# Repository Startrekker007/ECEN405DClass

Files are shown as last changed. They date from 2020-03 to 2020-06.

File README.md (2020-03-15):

# ECEN405DClass
This repository contains the documentation and designs for the Class D Amplifier design project for ECEN405.

## Directories
The Altium_Kicad directory contains circuit schematics.

The LTSpice dir contains all simulation schematics on LTSpiceXVII.

Assignment dir contains draft assignments

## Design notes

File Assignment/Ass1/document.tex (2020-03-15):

\documentclass[]{article}
\usepackage{float}
\usepackage{multicol}
\usepackage[a4paper, margin=0.68in]{geometry}
\usepackage[siunitx]{circuitikz}
\usepackage{siunitx}
\usepackage{tikz}
\usetikzlibrary{shapes,arrows}
\usepackage{verbatim}
\usepackage{lscape}
\usepackage{listings}
\usepackage{courier}
\usepackage{gensymb}
\usepackage{amsmath,amsfonts,mathtools,amssymb}
%opening
\title{ECEN405 Assignment 1}
\author{Keshav Raj 300418412\\Lab Partner: Tim Loretto}

\begin{document}
\tikzstyle{block} = [draw, fill=blue!20, rectangle, 
minimum height=3em, minimum width=6em]
\tikzstyle{sum} = [draw, fill=blue!20, circle, node distance=1cm]
\tikzstyle{input} = [coordinate]
\tikzstyle{output} = [coordinate]
\tikzstyle{pinstyle} = [pin edge={to-,thin,black}]
\maketitle

\begin{multicols}{2}
	\section{Question 1}
	\subsection{a)}
	In order to ensure 80W can be delivered to a $4\Omega$ impedance load, a value for the full voltage swing range must be calculated which allows enough current to flow through the load to dissipate 80W through it. The voltage must be within 33V which is the maximum that one channel of the power supply can output and the current must be less than 6A which is the maximum two of the banks hooked in parallel can output.
	The following is the calculation of the required values:
	\begin{equation*}
	\begin{split}
	80&=IV\\
	80&=4I^2\\
	\frac{80}{V}&=I\\
	80&=4\left( \frac{80}{V} \right)^2\\
	80&=4\left( \frac{6400}{V^2} \right)\\
	80&=\frac{25600}{V^2}\\
	\frac{25600}{80}&=V^2\\
	V&=\sqrt{320}\\
	V&=17.888V\\
	I&=4.472A\\  
	\end{split}
	\end{equation*}
	\subsection{b)}
	In order to achieve the 10Hz to 200Hz bandwidth, firstly the triangle wave generator must be a high enough frequency to modulate the input signal without causing any aliasing. In order to ensure this, the triangle wave must be at least 10 times greater than the highest frequency component of the input signal. However, without filtering the input, we cannot be sure what the highest frequency component could be, therefore a bandpass filter at the input is required. The following constitutes the design for a cascaded sallen-key lowpass and high pass filter which are both chebyshev 3th order filters.
\end{multicols}
	\begin{figure}[H]
		\centering
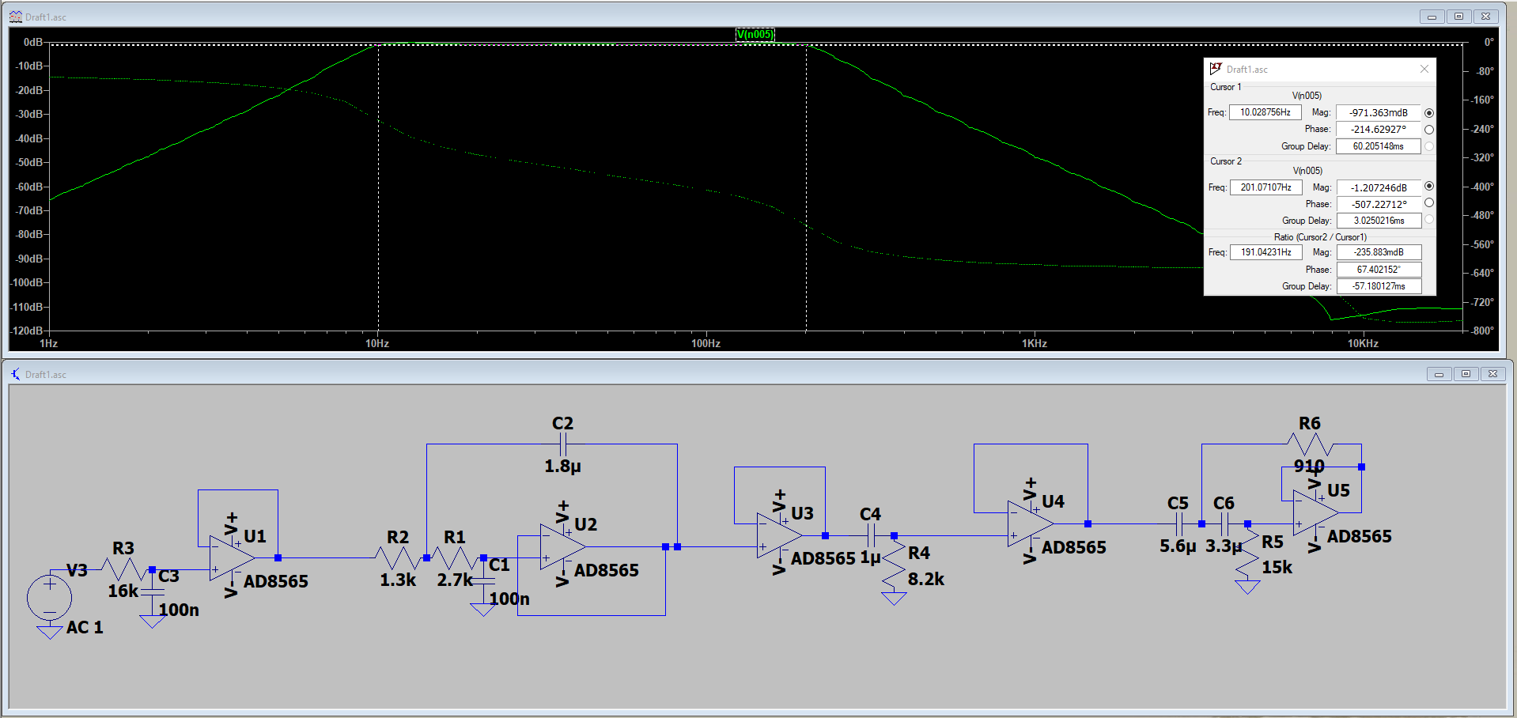
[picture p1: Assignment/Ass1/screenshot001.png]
		
		\caption{Designed Filter simulated in LTSpice}
		\label{fig:screenshot001}
	\end{figure}
\begin{multicols}{2}
	This would mean that the triangle wave can now be at a frequency of 2000Hz or greater to ensure correct modulation of the input signal.
	\subsection{c)}
	In order to ensure that a signal of 1V amplitude (or 2Vpp) can be modulated, the input triangle wave to the comparator must have an amplitude of slightly over 2V to prevent output saturation. A value of 2.1V for the maximum amplitude of the triangle wave will suffice. If the triangle wave's amplitude is unable to be easily adjusted, the passband gain of the input filters can instead be adjusted to achieve the same required comparator level.
	The triangle wave from the oscillator will have a DC offset that will likely be around 1V. This can either be AC coupled which will distort the triangle wave (as it is not a pure sinusoid) or the input signal can be offset as well to the same level, this can either be done using a clamping circuit (not preferred), a simple voltage divider with a DC decoupling capacitor or a summing amplifier. It is preferred to use a summing amplifier as the clamping circuit is difficult to implement while the decoupling capacitor acts as an extra low pass filter which may alter the expected spectrum of the input signal.
	These additions will ensure that the input signal and the triangle wave can be compared to each other easily with the comparator and ensure a full swing of PWM duty cycle with minimal wave clipping on the output.\\
	As gate driver generally accept a 3.3V or 5V logic signal, this PWM output must be amplified to one of the logic standards, this can be done with a simple non-inverting amplifier.
\end{multicols}
	\section{Q2}
	The following diagram shows the selected design:
	\begin{figure}[H]
		\centering
		
		\caption{D Class amplifier design}
		\label{fig:untitled-diagram-4}
	\end{figure}
\begin{multicols}{2}
	The first input low pass filter is a 3rd order chebyshev sallen-key topology filter. The output from this filter is cascaded with a voltage follower to a 10Hz high pass filter of the same type as the first low pass filter. The output from here can be offset if required to match the same offset of the triangle wave oscillator output.\\
	The triangle wave oscillator consists of a circuit that generates a triangle wave offset at a settable voltage, amplitude and frequency of oscillation using two trimmer potentiometers.\\
	The input signal after filtering is connected to the non-inverting input of the comparator while the triangle wave is connected to the inverting input of the comparator.
	The output of the comparator can be pulled high to a logic voltage using a pull-up resistor which can then be connected to a gate drivers' logic inputs.\\
	To realise a full bridge toplogy, two gate drivers are required to drive all the MOSFETs in the bridge. These driver's outputs are connected to the gates of the H-bridge with two bootstrap circuits for each pair of MOSFETs each gate driver is driving.\\
	Finally the output of the bridge will be connected to a high current low pass LC filter to filter out the PWM waveform and get back the modulated waveform. The cut off frequency of the LC filter can be as low as 200Hz however must be much lower than 2000Hz to ensure no spectral components of the PWM wave remains.\\
	\section{Q3}
	The decision of having a half bridge vs a full bridge topology consists of weighing what is most important in terms of features.\\
	A half bridge topology has the advantages of having lesser switching MOSFETs and therefore far lower switching and conduction losses resulting in an overall more efficient design. The disadvantages are that it requires feedback from the output signal to the input signal to ensure correct operation. It also requires a negative power supply rail which can be difficult to implement if more current is required from the power supply.\\
	A full bridge topology has the advantage of being open loop and doesn't require any feedback. The output voltage will swing from Vdd to GND and will not have any DC offset if correctly filtered.
	It therefore only requires a single power supply channel to realise. Overall it is infact easier to correctly implement and could potentially be more reliable.
	It's disadvantages include higher switching losses, requirement of an extra gate driver and more MOSFETs.\\
	In the end the full bridge topology was chosen in favor of simplicity and reliability and better audio quality. The output voltage swing is also preferably Vdd to GND and a separate negative rail is not required.
\end{multicols}

\end{document}

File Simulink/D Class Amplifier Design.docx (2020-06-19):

# D Class Amplifier Design

# Introduction

The development of power amplifiers is a very important in several applications within both engineering and music where they are used to drive high power motors or audio speakers. This report outlines our attempt at designing and simulating a D class amplifier with the specifications stated below:

- Input sensitivity: +-1V
- Power Output: 80W
- Twin 32V 3A power supply driven
- Bandwidth: 10Hz-200Hz Subwoofer specification

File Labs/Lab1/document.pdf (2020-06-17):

ECEN405 LAB 1 KESHAV RAJ 300418412 | 1

# ECEN405 Lab 1

Keshav Raj 300418412
Lab Partner: Tim Loretto
I. DELIVERABLES
A. 1)

30k =

10k
32.8k(1k)C1

30k =

10k
32.8M C1
1
C1

=

30k · 32.8M
10k

C1 =

10k
30k · 32.8M
C1 = 10.1626nF
C1 u 10nF
B. 2)
In order to find the minimum frequency, R3 needs to be minimized and R4 needs to be maximized. By entering the formula into desmos and assigning R3 to be the X axis and R4 an adjustable slider, the entire range of frequencies can be investigated.

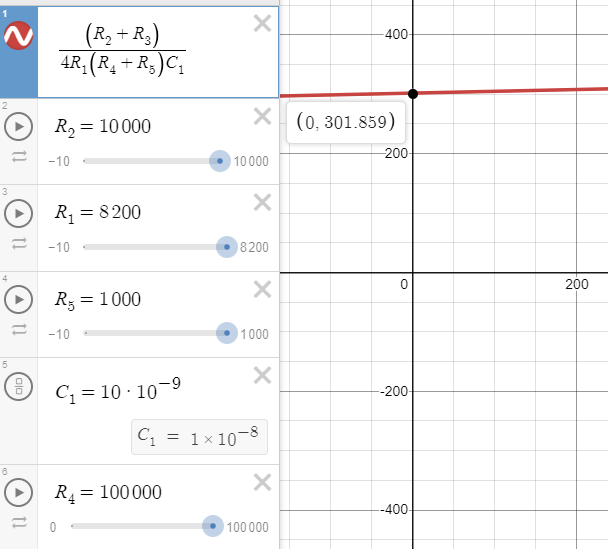
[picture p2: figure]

Fig. 1. Minimum frequency at R3 = 0Ω and R4 = 100kΩ

Fig. 2. Maximum frequency when R3 = 1MΩ and R4 = 0Ω

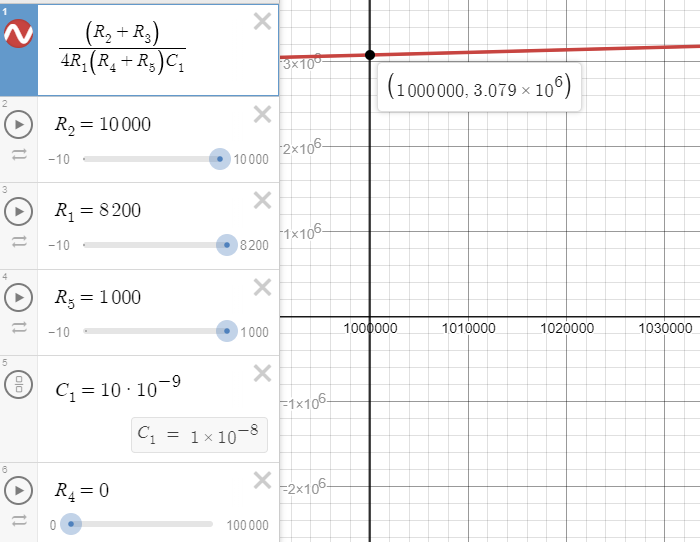
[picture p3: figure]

These two figures show that the minimum frequency is 301Hz while the max is 3MHz.

C. 3)

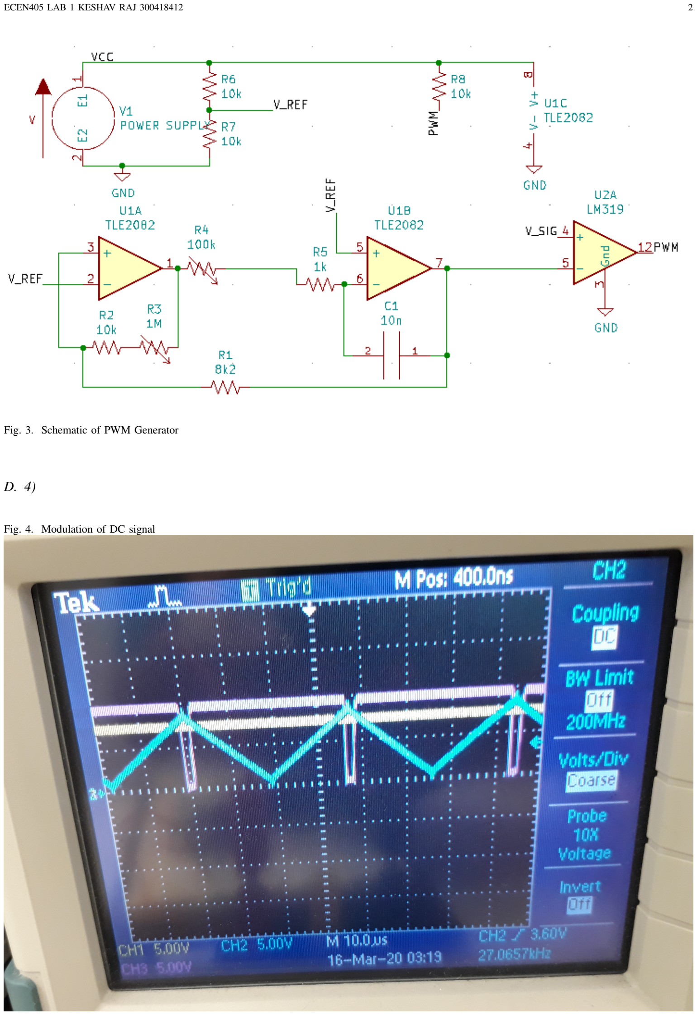
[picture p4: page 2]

Fig. 3. Schematic of PWM Generator

D. 4)

Fig. 4. Modulation of DC signal

E. 5)
All op-amps have a drop off in gain with increasing frequency, eventually as the frequency gets so high, the opamp’s gain attenuates too much too be seen on the output. Also the frequency response of some of the components used such as the resistors and capacitors would prevent the realization of high frequency signals and would most likely just filter them out.
F. 6)

Rather than having a single comparator, one can have two with the second one with its inputs swapped (input signal goes to inverting input and triangle wave goes to non-inverting input), this would allow a non-inverted and an inverted signal to be generated. Otherwise one could use a logic inverter to achieve the same.

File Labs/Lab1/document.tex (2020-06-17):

\documentclass[]{IEEEtran}
\usepackage{float}
\usepackage{multicol}
\usepackage[a4paper, margin=0.68in]{geometry}
\usepackage{color} %red, green, blue, yellow, cyan, magenta, black, white
\definecolor{mygreen}{RGB}{28,172,0} % color values Red, Green, Blue
\definecolor{mylilas}{RGB}{170,55,241}
\usepackage[siunitx]{circuitikz}
\usepackage{siunitx}
\usepackage{verbatim}
\usepackage{lscape}
\usepackage{listings}
\usepackage{courier}
\usepackage{gensymb}
\usepackage{amsmath,amsfonts,mathtools,amssymb}
%opening
\title{ECEN405 Lab 1}
\author{Keshav Raj 300418412\\Lab Partner: Tim Loretto}

\begin{document}
	\onecolumn
\lstset{language=Matlab,%
	%basicstyle=\color{red},
	breaklines=true,%
	morekeywords={matlab2tikz},
	keywordstyle=\color{blue},%
	morekeywords=[2]{1}, keywordstyle=[2]{\color{black}},
	identifierstyle=\color{black},%
	stringstyle=\color{mylilas},
	commentstyle=\color{mygreen},%
	showstringspaces=false,%without this there will be a symbol in the places where there is a space
	numbers=left,%
	numberstyle={\tiny \color{black}},% size of the numbers
	numbersep=9pt, % this defines how far the numbers are from the text
	emph=[1]{for,end,break},emphstyle=[1]\color{red}, %some words to emphasise
	%emph=[2]{word1,word2}, emphstyle=[2]{style},    
}
\maketitle
\markboth{ECEN405 LAB 1 KESHAV RAJ 300418412}
{}

\begin{multicols}{2}
\section{Deliverables}
\subsection{1)}
\begin{equation*}
	\begin{split}
		30k&=\frac{10k}{32.8k(1k)C_1}\\
		30k&=\frac{10k}{32.8M\ C_1}\\
		\frac{1}{C_1}&=\frac{30k\cdot32.8M}{10k}\\
		C_1&=\frac{10k}{30k\cdot32.8M}\\
		C_1&=10.1626nF\\
		C_1&\approxeq10nF\\
		\end{split}
\end{equation*}
\subsection{2)}
In order to find the minimum frequency, $R_3$ needs to be minimized and $R_4$ needs to be maximized. By entering the formula into desmos and assigning $R_3$ to be the X axis and $R_4$ an adjustable slider, the entire range of frequencies can be investigated.
\begin{figure}[H]
	\centering
	\caption{Minimum frequency at $R_3=0\Omega$ and $R_4=100k\Omega$}
	\label{fig:screenshot001}
	
\end{figure}
\begin{figure}[H]
	\centering
	\caption{Maximum frequency when $R_3=1M\Omega$ and $R_4=0\Omega$}
	\label{fig:screenshot002}
	
\end{figure}
These two figures show that the minimum frequency is 301Hz while the max is 3MHz.
\subsection{3)}

\end{multicols}
\begin{figure}[H]
	\centering
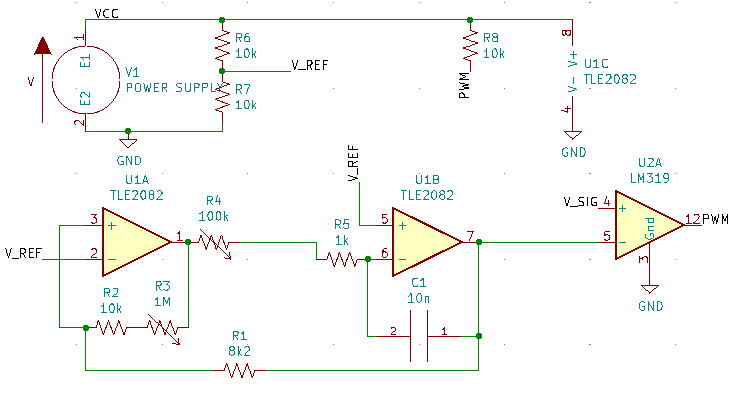
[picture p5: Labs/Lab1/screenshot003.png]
	
	\caption{Schematic of PWM Generator}
	\label{fig:screenshot003}
\end{figure}
\begin{multicols}{2}
	
\end{multicols}
	\subsection{4)}

\begin{figure}[H]
	\centering
	\caption{Modulation of DC signal}
	\label{fig:crossing}
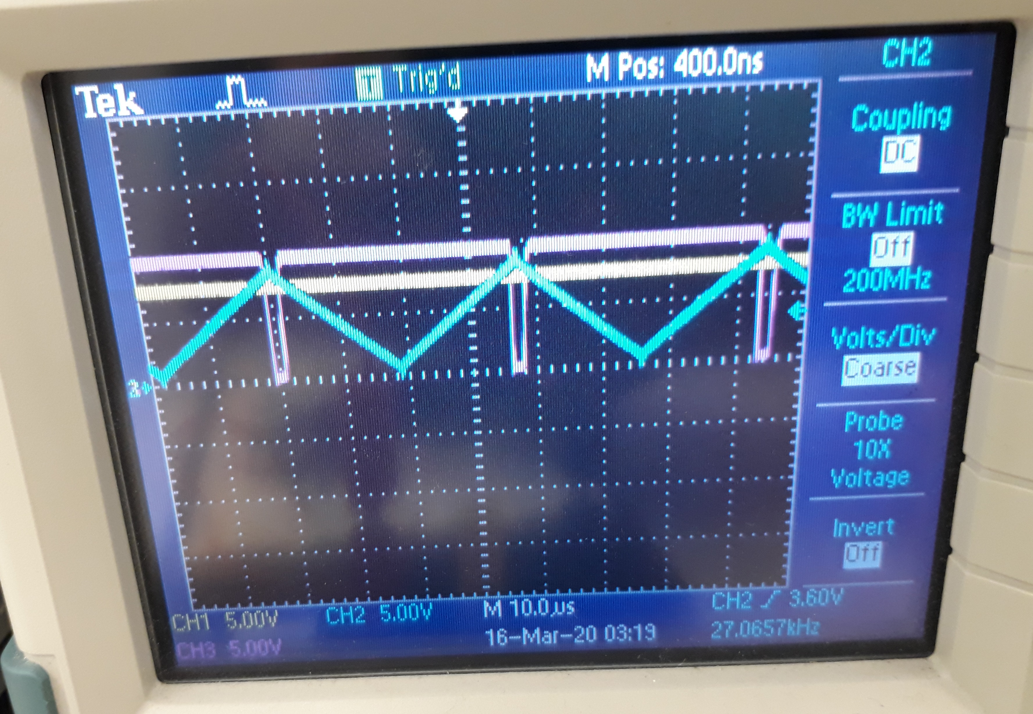
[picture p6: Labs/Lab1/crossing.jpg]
	
\end{figure}
	
\begin{multicols}{2}
	\subsection{5)}
	All op-amps have a drop off in gain with increasing frequency, eventually as the frequency gets so high, the op-amp's gain attenuates too much too be seen on the output. Also the frequency response of some of the components used such as the resistors and capacitors would prevent the realization of high frequency signals and would most likely just filter them out.
	\subsection{6)}
	Rather than having a single comparator, one can have two with the second one with its inputs swapped (input signal goes to inverting input and triangle wave goes to non-inverting input), this would allow a non-inverted and an inverted signal to be generated. Otherwise one could use a logic inverter to achieve the same.
\end{multicols}

\end{document}

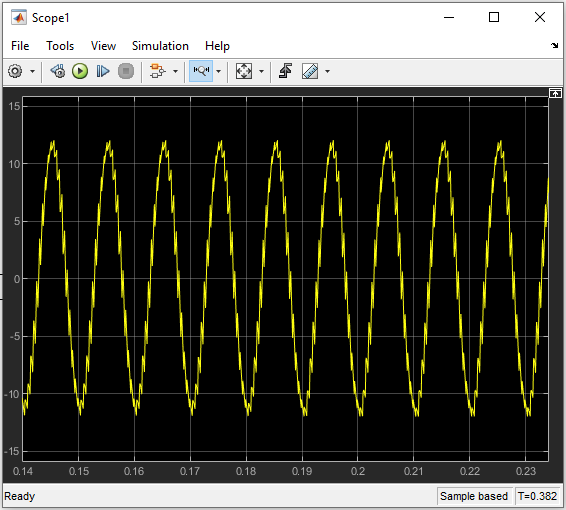
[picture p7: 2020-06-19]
Simulink/FinalPostFilterAdjustment.png

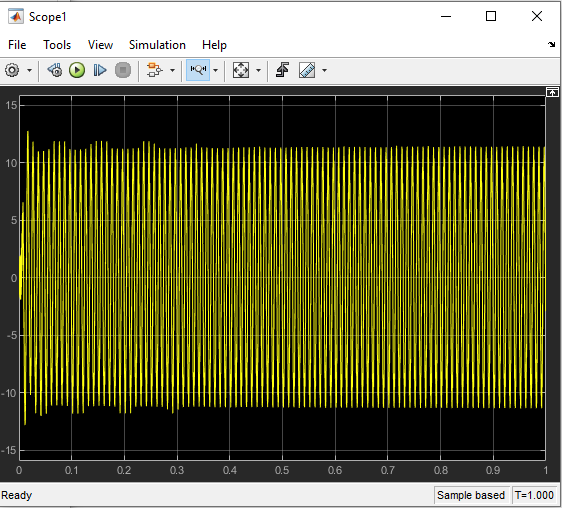
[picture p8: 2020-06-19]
Simulink/FinalOutput.png

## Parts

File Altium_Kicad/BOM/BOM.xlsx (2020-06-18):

ID | Component | Value | Quantity | Price Per Pack | No in Pack | Packs | Total Cost | Link
1 | Capacitor | 10n | 3 | 0.14 | 1 | 3 | 0.42 | https://nz.element14.com/multicomp/mc0805b103k500a5-08mm/ceramic-capacitor-0-01uf-50v-x7r/dp/1694099
2 | Capacitor | 100u | 1 | 0.92 | 1 | 1 | 0.92 | https://nz.element14.com/panasonic-electronic-components/eeufm1h101/aluminum-electrolytic-capacitor/dp/1219478
3 | Capacitor | 10u | 2 | 0.09 | 1 | 2 | 0.18 | https://nz.element14.com/multicomp/mcgpr63v106m5x11/cap-10-f-63v-20/dp/9451480
4 | Capacitor | 22u | 1 | 0.62 | 1 | 1 | 0.62 | https://nz.element14.com/panasonic/eeufm1h220/cap-22-f-50v-20/dp/1848399
5 | Capacitor | 1.8u ~ 1.5u | 1 | 1.75 | 5 | 1 | 1.75 | https://nz.element14.com/panasonic/ecea1hka1r5/cap-1-5-f-50v-20/dp/1902069
6 | Capacitor | 100n | 2 | 0.3 | 1 | 2 | 0.6 | https://nz.element14.com/multicomp/mc0805b104k500a2-54mm/capacitance-0-1-f/dp/2309020
7 | Capacitor | 5.6u | 1 | 0.64 | 1 | 1 | 0.64 | https://nz.element14.com/panasonic/eeufc2a5r6/cap-5-6-f-100v-20/dp/2805606
8 | Capacitor | 3.3u | 1 | 0.24 | 1 | 1 | 0.24 | https://nz.element14.com/united-chemi-con/ekmg201ell3r3mf11d/capacitor-alum-elec-3-3uf-200v/dp/1686773
9 | Capacitor | 1u | 1 | 0.09 | 1 | 1 | 0.09 | https://nz.element14.com/multicomp/mcrh63v105m5x11/cap-1-f-63v-20/dp/9452001
10 | Capacitor | 160u ~ 180u | 1 | 1.15 | 1 | 1 | 1.15 | https://nz.element14.com/panasonic/eeufr1v181b/cap-180-f-35v-20/dp/2479892
11 | Diode | 1N4007 | 2 | 0.12 | 1 | 2 | 0.24 | https://nz.element14.com/multicomp-pro/1n4007/diode-standard-recovery-1a-1kv/dp/230635701?st=1N4007
12 | Gate Driver | HIP4082IPZ | 1 | 8.26 | 1 | 1 | 8.26 | https://nz.rs-online.com/web/p/mosfet-drivers/0859391/
13 | Terminal Block |  | 2 | 1.78 | 1 | 2 | 3.56 | https://nz.element14.com/camdenboss/ctb5050-2/terminal-block-wire-to-brd-2pos/dp/2315342
14 | SMA |  | 1 | 6.77 | 1 | 1 | 6.77 | https://nz.element14.com/molex/73251-1150/rf-coax-conn-sma-jack-50-ohm-pcb/dp/1909295?st=sma
15 | Inductor | 1m | 1 | 10.56 | 1 | 1 | 10.56 | https://nz.rs-online.com/web/p/leaded-inductors/4890318/
16 | MOSFETS | STP40NF03L | 4 | 1.24 | 1 | 4 | 4.96 | https://nz.element14.com/stmicroelectronics/stp40nf03l/mosfet-n-to-220/dp/9803149
17 | Resistor | 10k | 4 | 0.04 | 1 | 4 | 0.16 | https://nz.element14.com/multicomp/mcmf0w8ff1002a20/metal-film-resistor-10kohm-125mw/dp/1127017
18 | resistor | 30k | 1 | 0.06 | 1 | 1 | 0.06 | https://nz.element14.com/multicomp/mf50-30k/res-30k-1-500mw-axial-metal-film/dp/9340378
19 | Resistor | 1k | 1 | 0.04 | 1 | 1 | 0.04 | https://nz.element14.com/multicomp/mccfr0s2j0102a20/carbon-film-resistor-1kohm-500mw/dp/1127904
20 | Resistor | 8.2k | 2 | 0.06 | 1 | 2 | 0.12 | https://nz.element14.com/multicomp/mf50-8k2/res-8k2-1-500mw-axial-metal-film/dp/9340947
21 | Resistor | 3.9k | 2 | 0.06 | 1 | 2 | 0.12 | https://nz.element14.com/multicomp/mf50-3k9/res-3k9-1-500mw-axial-metal-film/dp/9340521
22 | Resistor | 1.3k | 1 | 0.03 | 1 | 1 | 0.03 | https://nz.element14.com/multicomp/mccfr0w4j0132a50/carbon-film-resistor-1-3kohm-250mw/dp/1128774
23 | Resistor | 2.7k | 1 | 0.02 | 1 | 1 | 0.02 | https://nz.element14.com/multicomp/mcmf0w8ff2701a20/metal-film-resistor-2-7kohm-125mw/dp/1129191
24 | resistor | 16k | 1 | 0.06 | 1 | 1 | 0.06 | https://nz.element14.com/multicomp/mf50-16k/res-16k-1-500mw-axial-metal-film/dp/9340068
25 | Resistor | 910R | 1 | 0.06 | 1 | 1 | 0.06 | https://nz.element14.com/multicomp/mf50-910r/res-910r-1-500mw-axial-metal-film/dp/9340980
26 | Resistor | 15k | 1 | 0.03 | 1 | 1 | 0.03 | https://nz.element14.com/multicomp-pro/mcmf0w4ff1502a50/metal-film-resistor-15kohm-250mw/dp/112693801
27 | Resistor | 5k | 1 | 0.55 | 1 | 1 | 0.55 | https://nz.element14.com/multicomp-pro/mcmf0w4bb5001a50/metal-film-resistor-5kohm-250mw/dp/160205801
28 | Switch | OS102011MS2QN1C | 1 | 1.31 | 1 | 1 | 1.31 | https://nz.rs-online.com/web/p/slide-switches/7874864/
29 | OOOP AMP | LM324N | 3 | 1.36 | 1 | 3 | 4.08 | https://nz.element14.com/on-semiconductor/lm324n/ic-op-amp-quad-dip14-324/dp/1417640?st=LM324N
30 | Comparator | MCP6541-E/P | 1 | 0.94 | 1 | 1 | 0.94 | https://nz.element14.com/microchip/mcp6541-e-p/comparator-single-push-pull-dip8/dp/1332135
31 | LR | LM7805CT | 1 | 1.09 | 1 | 1 | 1.09 | https://nz.element14.com/stmicroelectronics/l7805abv/ic-v-reg-5v/dp/1467758
32 | SMR | R-785.0-0.5 | 1 | 14.57 | 1 | 1 | 14.57 | https://nz.element14.com/recom-power/r-785-0-0-5/converter-dc-dc-5v-3w/dp/1793142
33 | LR | LM7812CT | 1 | 1.28 | 1 | 1 | 1.28 | https://nz.element14.com/on-semiconductor/mc7812ctg/ic-v-reg-12v-7812-to-220-3/dp/9666109
34 | Inverter | SN74HC04N | 1 | 1.15 | 1 | 1 | 1.15 | https://nz.element14.com/texas-instruments/sn74hc04n/ic-hex-inverter-74hc04-dip14-5v/dp/3120432
TOTAL COST
66.63

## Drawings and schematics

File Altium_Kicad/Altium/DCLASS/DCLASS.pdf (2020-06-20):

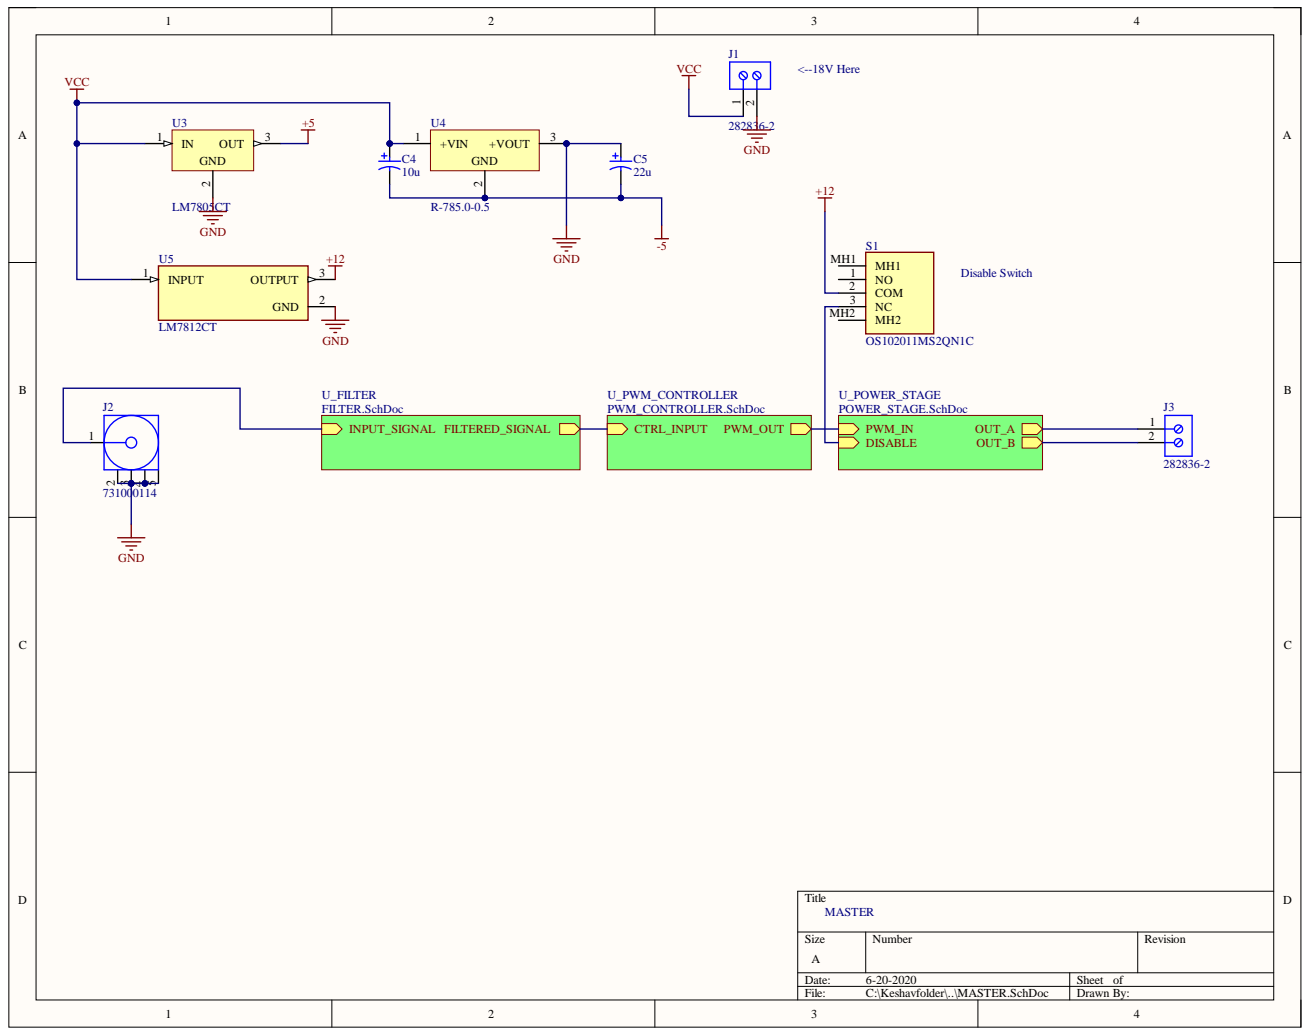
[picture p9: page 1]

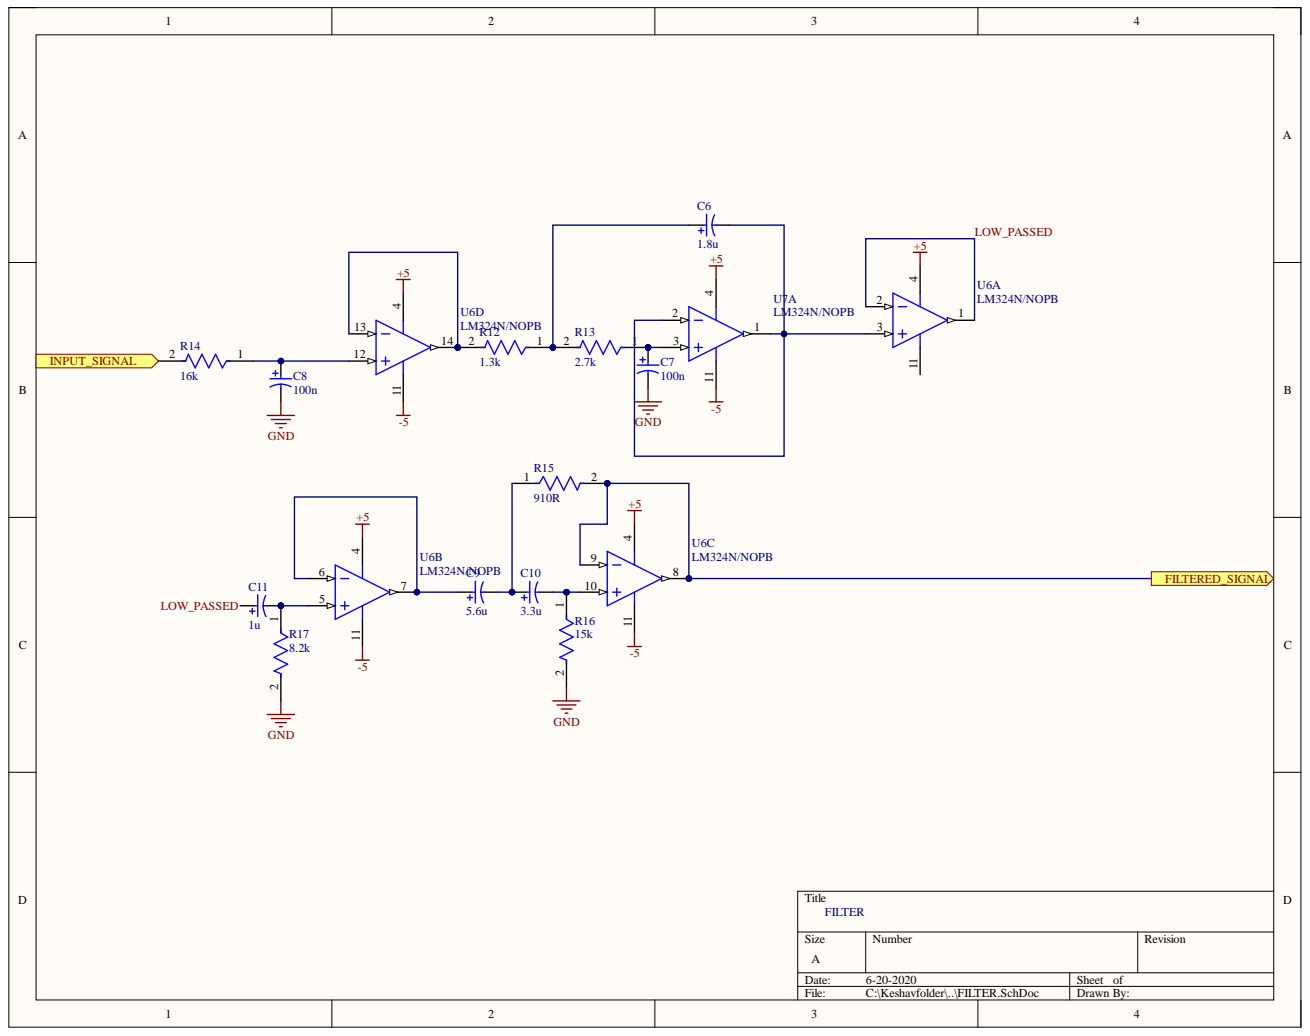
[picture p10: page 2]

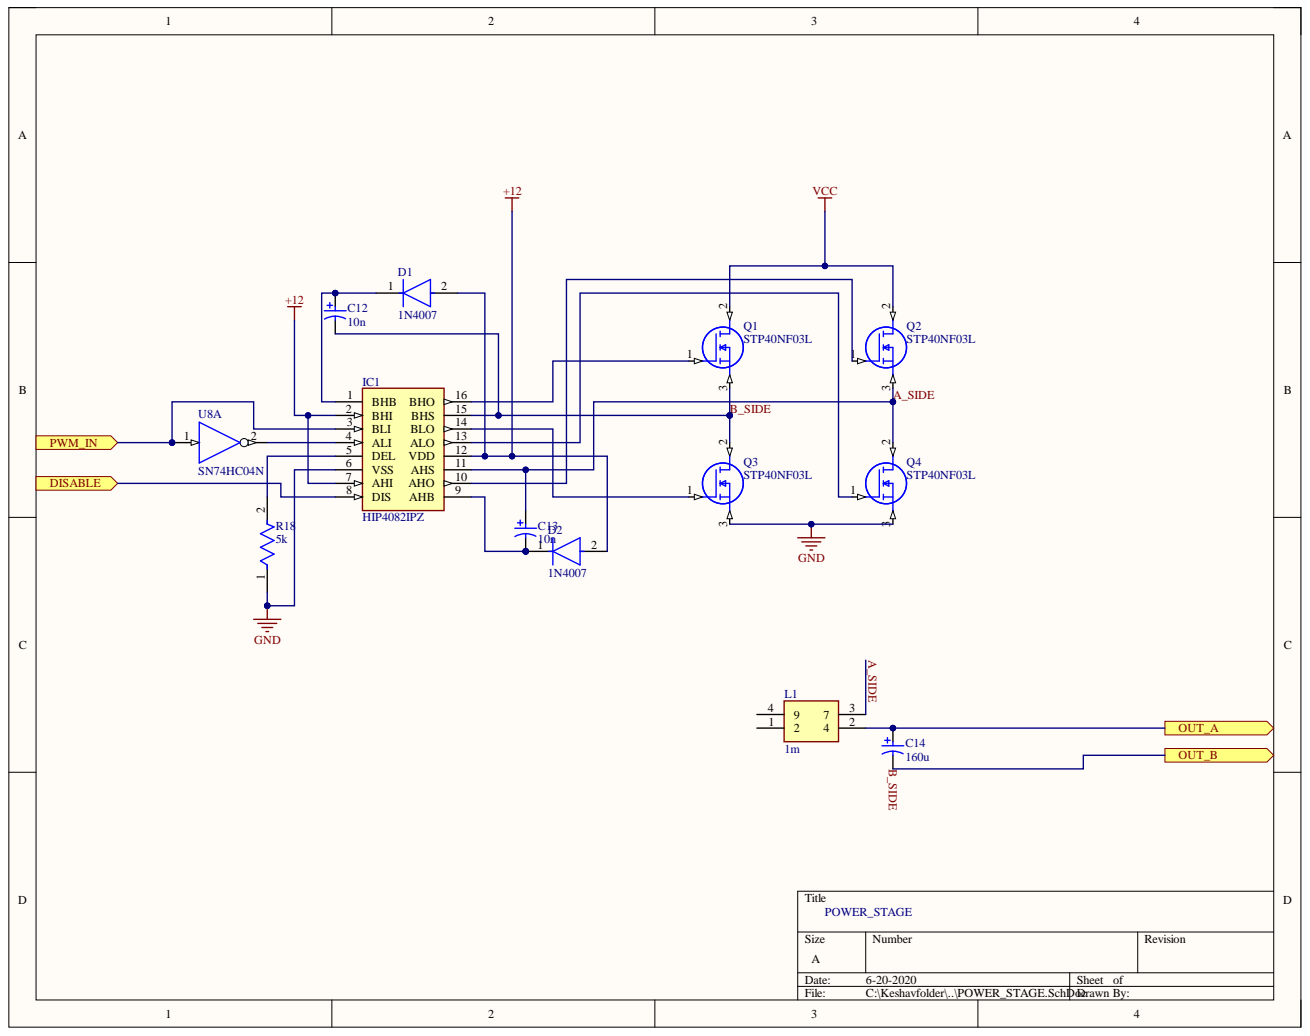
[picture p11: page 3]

3 | IC1 HIP4082I BH I BH O BL I BL O A L I A L D E L V D V S S A H S O A H I A H D I S A H B | | 14
BH | S
2 | | | 15 | | B_S I D E Q 3

6 | | 1 1
7 | | 10 | | S T P40N F03L

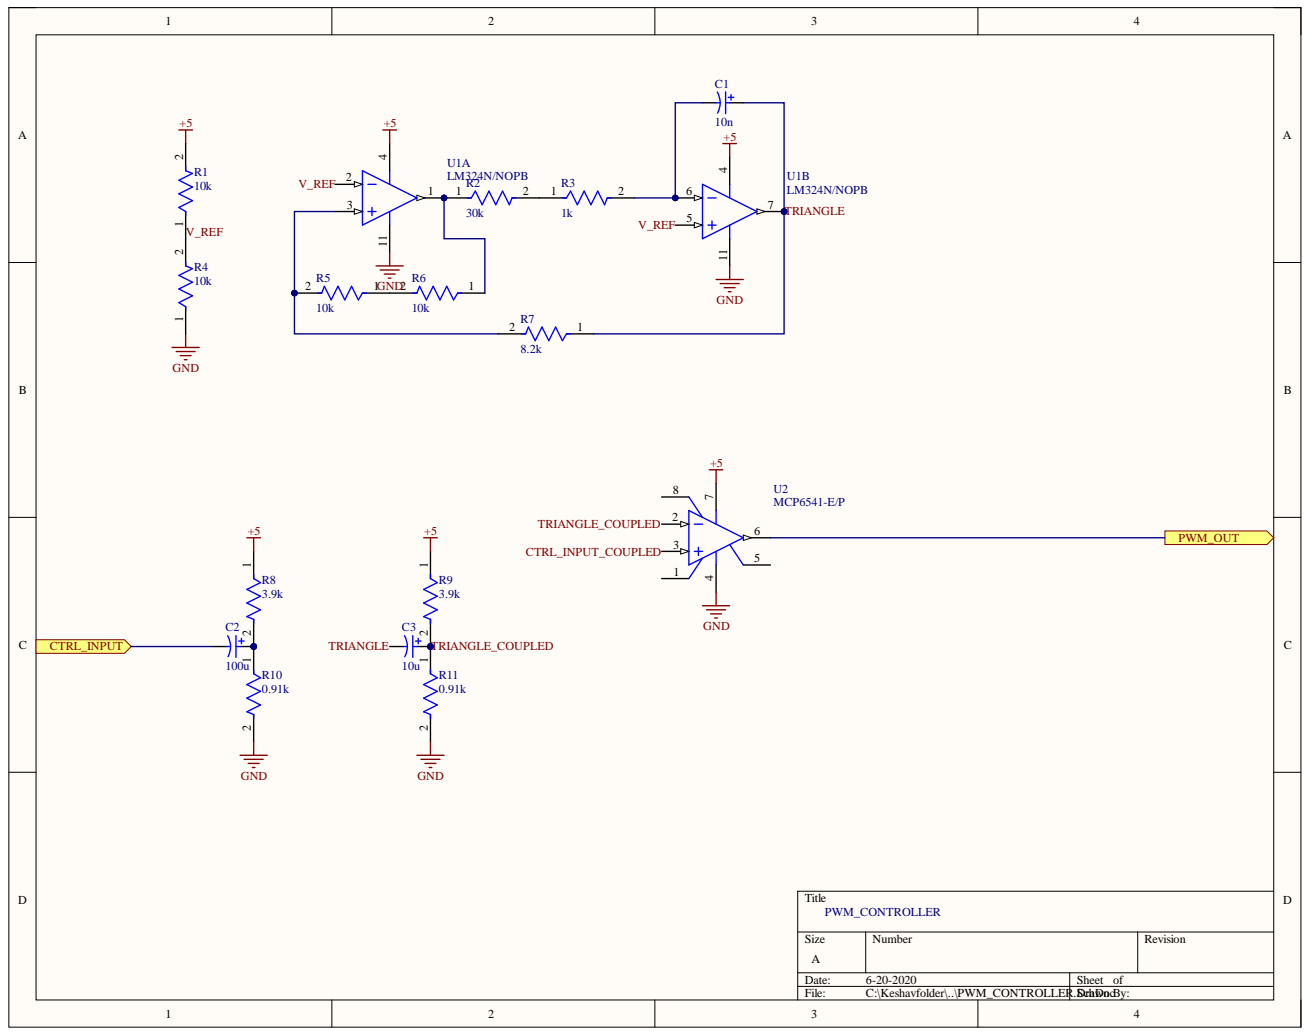
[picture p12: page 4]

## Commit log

2020-03-15 Adding draft and spice designs and pwm schematic
    [pwm.kicad_pcb, pwm.sch]
2020-03-15 Draft lab, fixed PWm gen schematic by adding rail definition
    [pwm.sch]
2020-06-18 Done D class amp and BOM
    [BOM.xlsx, DCLASS.PrjPcb, FILTER.SchDoc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]
